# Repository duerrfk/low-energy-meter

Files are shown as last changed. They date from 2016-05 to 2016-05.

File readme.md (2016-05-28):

# What is Low-Energy-Meter?

Low-Energy-Meter is a tool for measuring the energy consumption of low-energy devices using a Raspberry Pi. In particular, it was developed to measure the energy consumption of battery-powered Bluetooth Low Energy (BLE) devices.

Low-energy devices switch frequently between active mode and power-save mode striving for minimum duty cycles. The energy consumption differs significantly by several orders of magnitude between active mode and power-save mode (milli-amps vs. micro-amps). This makes energy measurements challenging. For instance, it is hard to dimension a shunt resistor for measuring the voltage drop along the resistor to calculate current as I = V/R. If the shunt resistor is optimized for active mode, the voltage drop will be very low in power-save mode and thus hard to measure. If the shunt resistor is optimized for power-save mode, the voltage drop will be very large in active mode, and the device only runs at significantly reduced voltage possibly dropping below the threshold where brownout reset engages. 

Therefore, we use a different method to measure the energy consumption. We use a large capacitor (C = 10000 uF) as power supply. The energy stored in a capacitor can be calculated as E = 0.5\*C\*V^2. Thus, knowing the time period (t) that it takes to drop from a certain initial voltage (V_upper) to a certain lower voltage (V_lower), we can calculate the energy consumed in period t as E_delta = 0.5\*C\*(V_upper^2-V_lower^2) and the average power consumption as P_avg = E_delta/t. The energy consumption naturally includes the energy spent in active mode as well as power-save mode. So the basic idea is to first charge the capacitor from a "real" power supply (voltage regulator of the Raspberry Pi) and then discharge the capacitor via the device under test. While discharging, we periodically measure the voltage of the capacitor. When the voltage drops below a certain threshold somewhere above the critical brownout detection threshold, we automatically charge the capacitor again and start a new measuring cycle. 

One might argue that the capacitor is prone to self-discharging. However, experiments showed that this effect is very small, even smaller than the energy consumption in power-save mode and much smaller than the energy consumption in active mode, and thus negligible for our purpose. TODO: Prove this claim.

Low-Energy-Meter consists of two parts:

* Measurement hardware connected to the Raspberry Pi. The measurement hardware is basically a circuit board (PCB) with an analog-to-digital converter (ADC), the 10000 uF supply capacitor and some more components to support automatic measurements by repeatedly charging the supply capacitor and sampling the capacitor voltage while discharging the capacitor. The measurement board is depicted in the images below with a simple resistor connected as load ("device under test"). Schematics and PCB layout of the PCB are included.
* Software for the Raspberry Pi that automates the process of charging and sampling the supply capacitor and logging samples to the SD card.

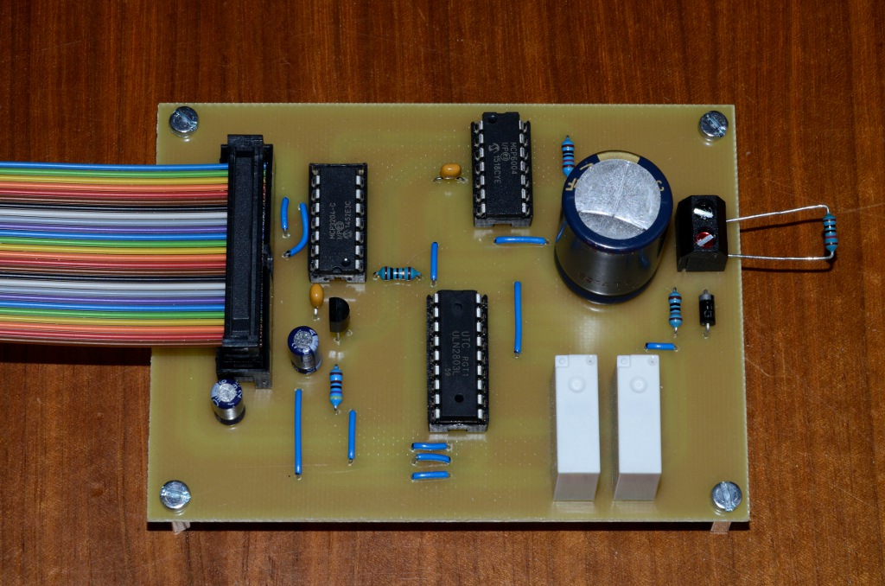
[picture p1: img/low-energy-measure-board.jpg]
Measurement Board


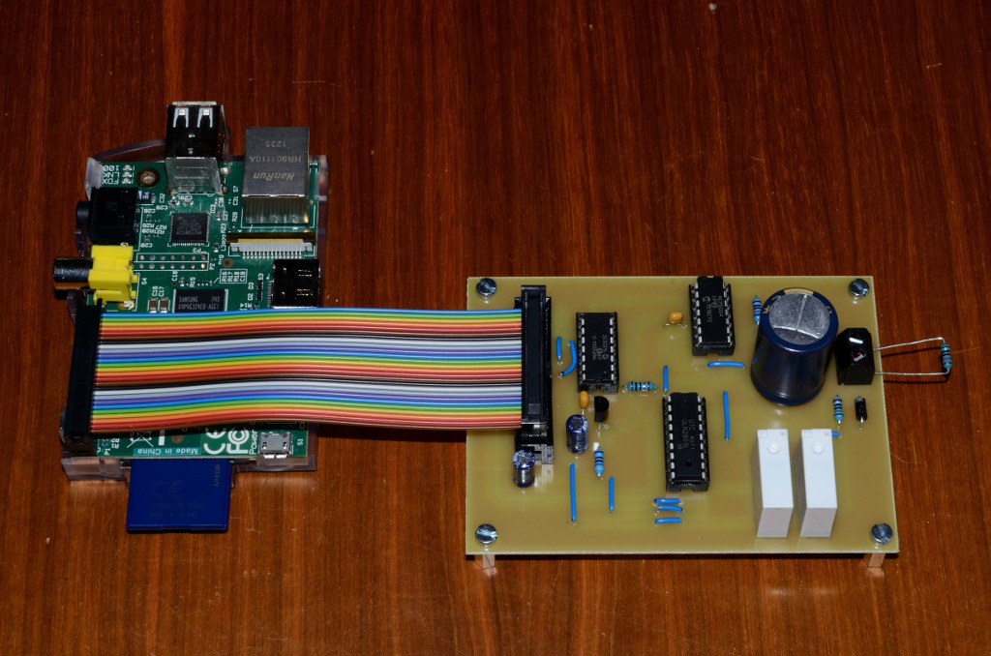
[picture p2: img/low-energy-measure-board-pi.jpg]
Measurement Board connected to Raspberry Pi


# The Hardware: Measurement Board

We use a capacitor of 10000 uF to power the device under test. This is large enough to run a BLE device for several minutes (using reasonable power-saving techniques) while voltage drops from say 3.0 V to 2.0 V. This capacitor is charged via a 160 Ohm resistor making sure not to overload the 3.3 V power rail of the Raspberry Pi. Since we charge the capacitor from the 3.3 V rail, 3.3 V is the maximum voltage we can supply to the device under test. For the BLE target devices and most MCUs this is a suitable voltage.
 
The measurement board is connected to a Raspberry Pi Model B (a single core Pi is good enough for 1 kHz sampling rate). It includes a 12 bit ADC (MCP6008 or MCP6004) to sample the voltage of the supply capacitor and transmit voltage samples to the Raspberry Pi via SPI.

Moreover, it includes two relays, one for charging the capacitor and powering the device under test while charging, and one for connecting the supply capacitor to the device under test when the capacitor has been charged for measuring the energy consumption. Both relays are controlled from two GPIOs of the Raspberry Pi to automate the process of charging and sampling while discharging the capacitor. An ULN2803 is used to drive the relays. 

A precise 2.5 V voltage reference (LM385) is used as reference for the ADC.

The board layout is optimized for simple etching (alternatively, you can send the Gerber files to a PCB manufacturer of your choice). Moreover, we only use easily available standard components. 

# The Software

Low-Energy-Meter includes a command line tool to automate the process of charging and sampling the supply capacitor and logging samples to a file.

The software tool called low-energy-meter can be found in folder src. 

## Compiling Low-Energy-Meter Tool

As a prerequisite, you need the [bcm2835 library](http://www.airspayce.com/mikem/bcm2835/). After installing the library, you can compile the tool with the following command:

    $ make low-energy-meter

## Running Low-Energy-Meter Tool

For precise sampling intervals, we recommend to use the RTPREEMPT patch for Linux (instructions on how to compile an RTPREEMPT kernel can be found on [this web-site](http://www.frank-durr.de/?p=203). 

The command line tool uses the following arguments:

* ```-f SAMPLING_FREQUENCY```: Sampling frequency. 1 kHz seems to be a safe upper bound where the Raspberry Pi can still deterministically meet the 1 ms sampling interval.
* ```-o FILE```: Output file for logging samples.
* ```-l THRESHOLD_LOWER```: Lower voltage threshold (ADC count) defining when the supply capacitor is recharged.
* ```-u THRESHOLD_UPPER```: Upper threshold (ADC count) defining when a discharging (sampling) cycle starts.

ADC counts can be translated to voltage thresholds as follows: V = 5.0 V \* 4095/ADCCount

Note that the reference voltage of the ADC is 2.5 V and we divide the voltage sampled by the ADC by 2 to stay within the allowed voltage range of max. 2.5 V. Therefore, an ADC count of 4095 corresponds to 5 V.  
    
The format of the output file is CSV (comma-separated values) with the following values per sample: 

* Timestamp of the sample in nanoseconds.
* Epoch (discharging cycle). Measurements are only recorded while discharging, i.e., while powering the device under test from the capacitor.
* ADC count, which can be translated to capacitor voltage by calculating V = 5.0 V \* 4095/ADCCount.

# Measurement Example

The following example shows how to take measurements, and how to evaluate them using [R](https://www.r-project.org/). In this example, we measure the energy-efficiency of the [Faros]() Bluetooth Low Energy Beacon implementing Google's Eddystone standard. The data of this experiment is available in folder data. 

## Step 1: Taking measurements

We take measurements with 1000 Hz sampling frequency, and lower and upper voltage thresholds of 2.0 V (ADC count = 2.0 V / 5.0 V \* 4095 = 1638) and 3.2 V (ADC count = 2621), respectively, i.e., the device under test is running from voltages in this range. The Faros beacon can be operated down to 1.8 V, so re-charging the capacitor at 2.0 V leaves enough headroom to ensure that the beacon will not reset. We also provide the data set of this experiment in folder data, so you can follow the steps below.

    $ sudo ./low-energy-meter -f 1000 -l 1638 -u 2621 -o faros.csv -p 80

## Step 2: Loading the CSV data into R.

    $ R
    $ x <- read.csv(file="faros.csv",head=FALSE,sep=",")

After this step, you will find all data in data frame x, which is basically a table with three rows called x$V1 (timestamp in nanoseconds), x$V2 (measurement cycle), and x$V3 (ADC count of voltage measurements).

## Step 3: Selecting data for evaluation

We will select data from one measurement cycle in a certain voltage range between 2.0 V (ADC count 1638) and 3.0 V (ADC count 2457).

    $ y = subset(x, x$V2==2 & x$V3 >= 1638 & x$V3 <= 2457)

The selected data is now in data frame y. For visual inspection, you can plot the voltage (ADC counts) over time using the following command:

    $ plot(y$V1/1000000000-min(y$V1)/1000000000, y$V3/4095*5.0, xlab="t [s]", ylab="Voltage [V]")

The following plot shows the measurements taken for the Faros beacon.

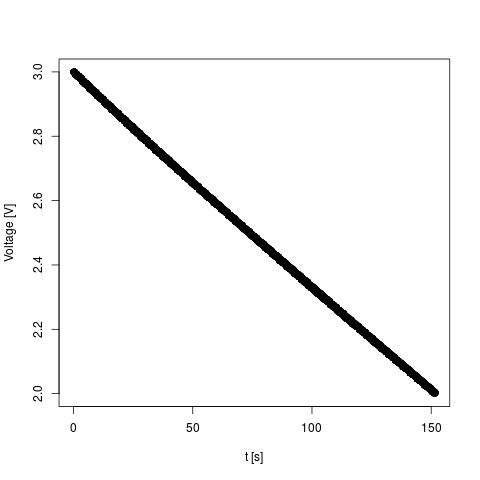
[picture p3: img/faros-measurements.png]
Faros beacon measurements


## Step 4: Calculating consumed energy and average power consumption

First, we determine the maximum and minumum voltage of the selected sample interval:

    $ max(y$V3)
    [1] 2457
    $ min(y$V3)
    [1] 1638

So the maximum and minumum voltages are V_max = 2457/4095 \* 5.0 V = 3.0 V and V_min = 1638/4095 \* 5.0 V = 2.0 V, respectively.

Then, we calculate the time t that it took to drop from V_max to V_min:

    $ (max(y$V1)-min(y$V1))/1000000000
    151.715
 
So it took t = 151.715 s.

Since we know the capacity of the supply capacitor (10000 uF), we can calculatete the energy spent in this time interal as:

E = 0.5\*10000 uF\*(3.0 V)^2 - 0.5\*10000 uF\*(2.0 V)^2 = 0.025 J

The average power consumption is then calculated as:

P_avg = E/t = 0.025 J / 151.715 s = 164.78 uW

So if the Faros BLE beacon is powered from AA-size batteries (two connected in series to provide a nominal voltage of 3.0 V) with say 2.60 Wh energy, the beacon could run for about 657 days or 1.8 years.

# Voltage Leakage

One might argue that this measurement method is prone to inaccuracies because of self-discharging effects, bias current flowing into or out of the opamp connected to the capacitor (which according to the datasheet of the MCP6001 should be in the order of pA, so possibly not the biggest effect), etc. In order to evaluate these undesired effects, we took measurements without any load connected, where we would expect (ideally) the power consumption to be zero. The data is included in the data folder. The figure below depicts the result.

We can see that the capacitor discharged from initially V_max = 3.300 V to V_min = 3.066 V over a time period of t = 27926 s = 7.76 h. Hence, the energy consumed in this period is 0.0074 J, and the average power consumption is 266.713 nW. So giving some safety-margin, we can assume an accuracy of power measurements of about 1 uW. 

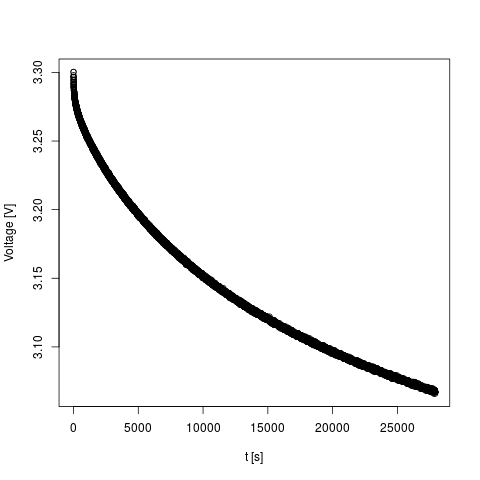
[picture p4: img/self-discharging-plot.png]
Self-discharging of capacitor


# Limitations

This measurement method is targeting low-energy devices, in particular, BLE devices. We make the following assumptions:

* The device under test can run from varying voltages in a range from 3.3 V to some lower threshold. Typical lower thresholds of MCUs used in BLE devices are as low as 1.8 V. For devices requiring more than 3.3 V (like for instance a Raspberry Pi, which is powered from 5.0 V USB), the circuit is not suitable.
* The device under test consumes little power up to tens of milliamps over the desired voltage range. Otherwise, the supply capacitor does not provide enough energy to run the device for a longer period including all operational modes (active and power-save mode). Up to tens of milliamps are typical values for active BLE devices with active MCU and radio (in power-save mode, the current is much lower down to micro-amps).    

# Licensing

Low-Energy-Meter uses two licenses for open hardware and software, respectively:

* The software (source code) is licensed under the Apache License 2.0
* The hardware (schematic diagrams, circuit board layouts, hardware documentation) is licensed under the CERN Open Hardware Licence v1.2

Both licenses are included in the repository.

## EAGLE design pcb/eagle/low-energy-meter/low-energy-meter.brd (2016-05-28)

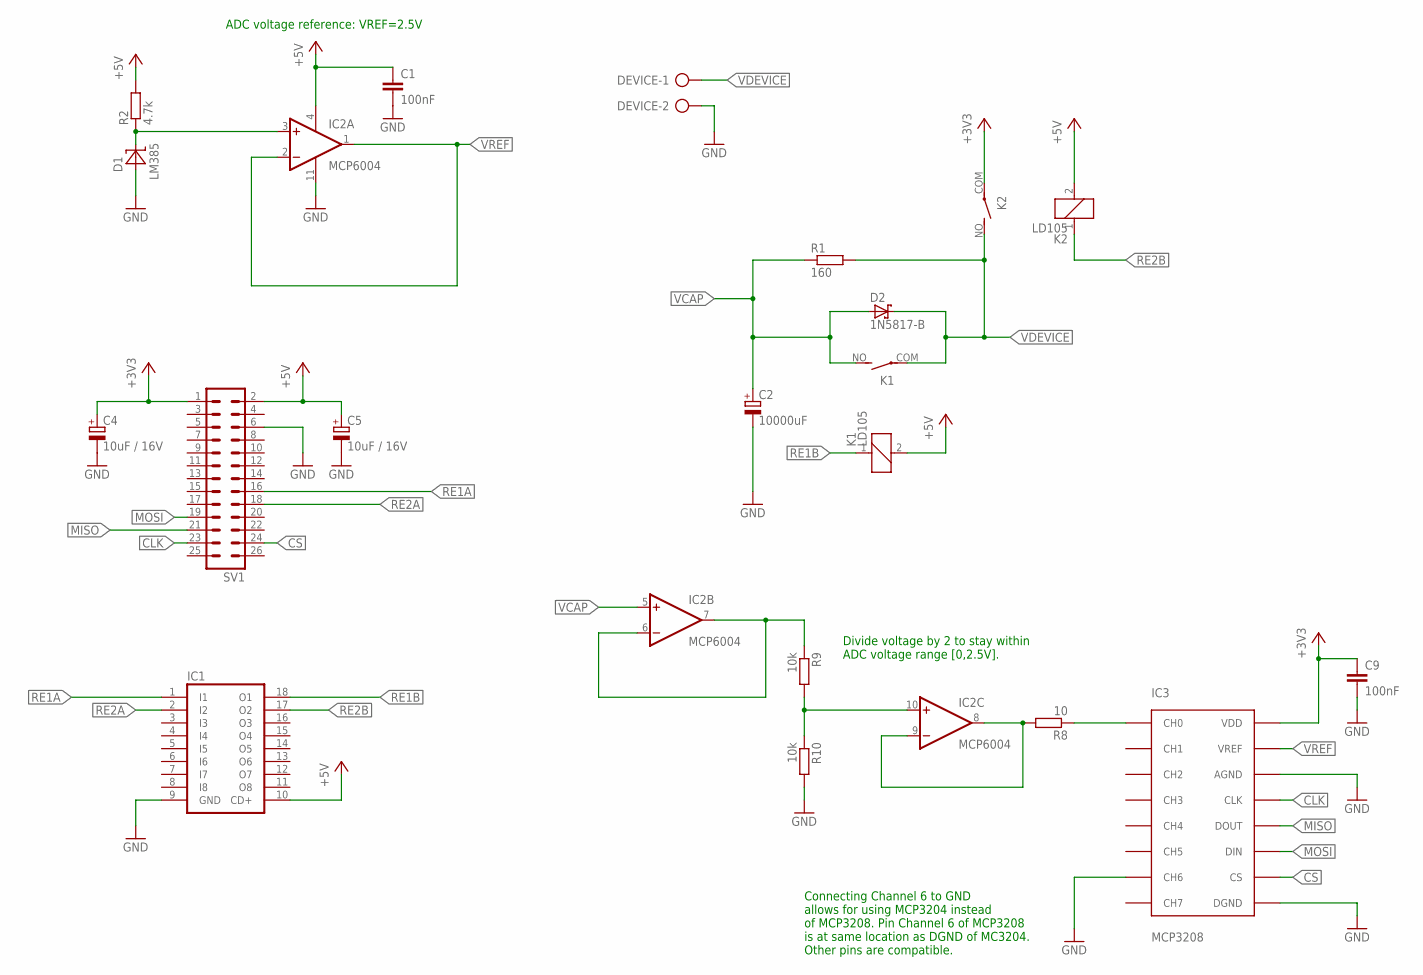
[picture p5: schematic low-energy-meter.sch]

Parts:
C1, C9: 100nF; C050-024X044
C2: 10000uF; E7,5-18
C4, C5: 10uF / 16V; E2,5-6
D1: LM385; TO-92
D2: 1N5817-B; DO41-7.6
DEVICE: AK500/2
IC1: ULN2803A; DIL18
IC2: MCP6004; DIL14
IC3: MCP3208; DIL16
K1, K2: LD105; LD
R1: 160; 0207/7
R2: 4.7k; 0207/7
R8: 10; 0207/7
R9, R10: 10k; 0207/7
SV1: ML26

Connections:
+3V3: C4.+, C9.1, IC3.VDD, K2.COM, SV1.1
+5V: C1.1, C5.+, IC1.10 (CD+), IC2.4 (V+), K1.2, K2.2, R2.2, SV1.2
CLK: IC3.CLK, SV1.23
CS: IC3.CS, SV1.24
GND: C1.2, C2.-, C4.-, C5.-, C9.2, D1.+, DEVICE.2, IC1.9 (GND), IC2.11 (V-), IC3.AGND, IC3.CH6, IC3.DGND, R10.2, SV1.6
MISO: IC3.DOUT, SV1.21
MOSI: IC3.DIN, SV1.19
unnamed: IC2.6 (-IN), IC2.7 (OUT), R9.1
unnamed: IC2.10 (+IN), R9.2, R10.1
unnamed: IC3.CH0, R8.1
unnamed: IC2.8 (OUT), IC2.9 (-IN), R8.2
unnamed: D1.-, IC2.3 (+IN), R2.1
RE1A: IC1.1 (I1), SV1.16
RE1B: IC1.18 (O1), K1.1
RE2A: IC1.2 (I2), SV1.18
RE2B: IC1.17 (O2), K2.1
VCAP: C2.+, D2.A, IC2.5 (+IN), K1.NO (S), R1.1
VDEVICE: D2.C, DEVICE.1, K1.COM, K2.NO (S), R1.2
VREF: IC2.1 (OUT), IC2.2 (-IN), IC3.VREF

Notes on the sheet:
ADC voltage reference: VREF=2.5V
Divide voltage by 2 to stay within ADC voltage range [0,2.5V].
Connecting Channel 6 to GND allows for using MCP3204 instead of MCP3208. Pin Channel 6 of MCP3208 is at same location as DGND of MC3204. Other pins are compatible.

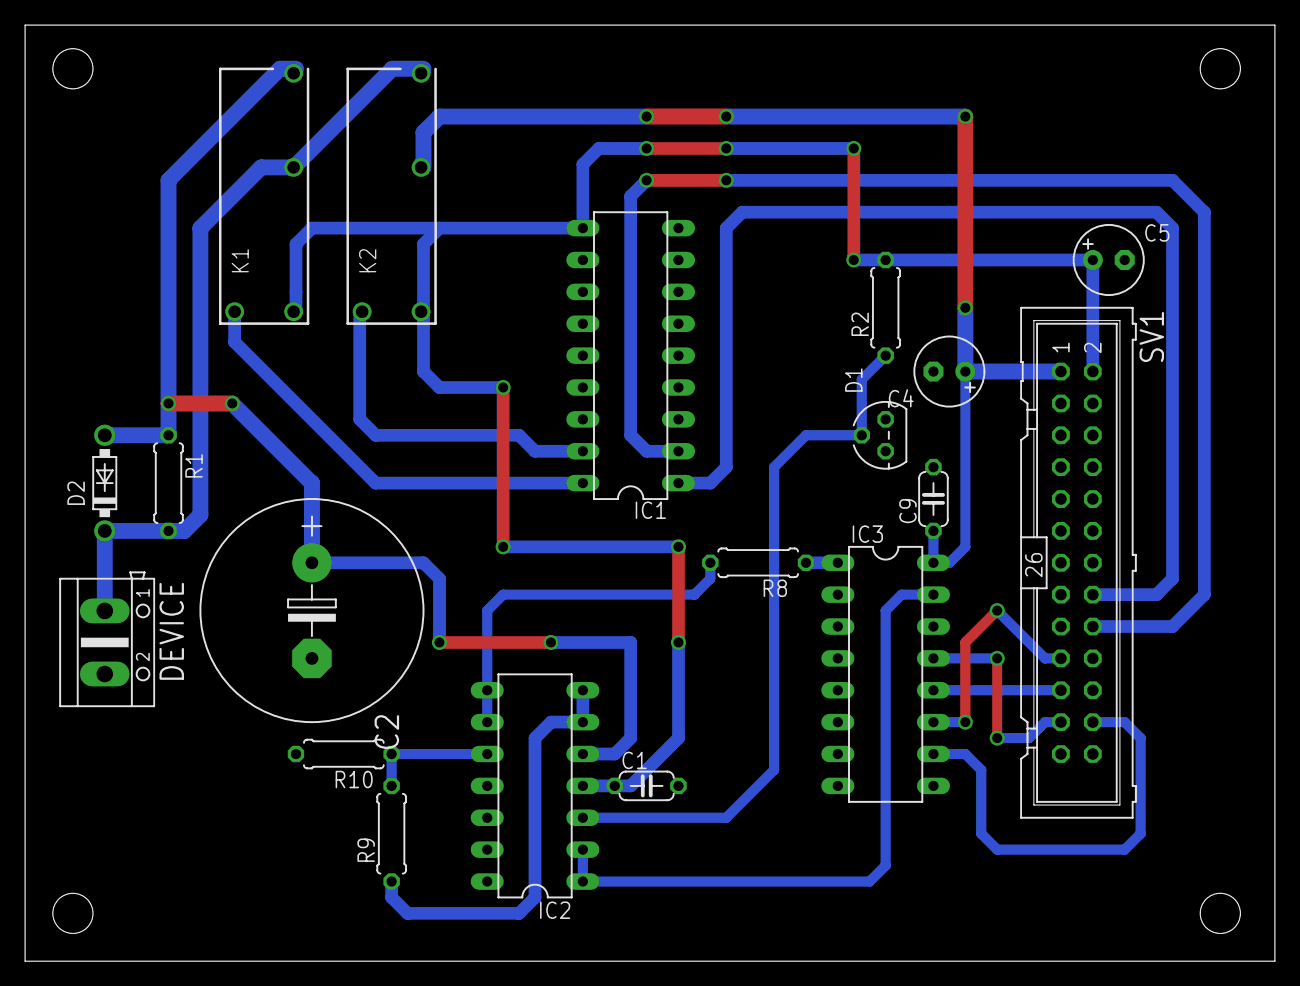
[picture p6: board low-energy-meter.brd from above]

Board: 2 copper layers, 99.6 x 74.6 mm, 19 parts (0 on the bottom side), 19 nets.

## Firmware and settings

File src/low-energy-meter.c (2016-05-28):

/**
 * This file is part of Low-Energy-Meter.
 *
 * Copyright 2016 Frank Dürr
 *
 * Licensed under the Apache License, Version 2.0 (the "License");
 * you may not use this file except in compliance with the License.
 * You may obtain a copy of the License at
 * 
 * http://www.apache.org/licenses/LICENSE-2.0
 * 
 * Unless required by applicable law or agreed to in writing, software
 * distributed under the License is distributed on an "AS IS" BASIS,
 * WITHOUT WARRANTIES OR CONDITIONS OF ANY KIND, either express or implied.
 * See the License for the specific language governing permissions and
 * limitations under the License.
 */

#include <bcm2835.h>
#include <stdlib.h>
#include <unistd.h>
#include <stdio.h>
#include <string.h>
#include <time.h>
#include <stdbool.h>
#include <signal.h>
#include <sched.h>
#include <sys/mman.h>
#include <stdbool.h>
#include "mcp320x.h"
#include "ring.h"

/* Default task priority */
#define DEFAULT_TASK_PRIORITY 49

/* Estimated maximum stack size */
#define MAX_STACK_SIZE (RING_SIZE*sizeof(struct ring_entry) + 1024) 

/* GPIO pins controlling charge and discharge relay */
const RPiGPIOPin charge_pin = RPI_GPIO_P1_18; 
const RPiGPIOPin discharge_pin = RPI_GPIO_P1_16; 

/* ADC channel measuring voltage of capacitor / device */
const enum channel_singleended adc_channel = CH0;

/* SPI settings. */
/* The Raspberry Pi has two SS pins called CE0 and CE1. 
   The board uses CE0 (BCM2835_SPI_CS0). */
const bcm2835SPIChipSelect spi_cs = BCM2835_SPI_CS0;
/* Since we operate the MCP3208 at 3.3 V, the SPI clock rate should be <= 1 MHz 
   (cf. MCP3208 datasheet). 500 kHz should be a safe setting. */
const unsigned int spi_frequency = 500000;

FILE *fout = NULL;

int task_priority;
struct timespec sampling_interval;
double sampling_frequency;

uint16_t threshold_upper;
uint16_t threshold_lower;

struct ring the_ring;

pthread_t sampling_thread;
pthread_t logger_thread;

bool is_spi_open = false;
bool is_bcm_open = false;

/**
 * Gracefully terminate the process.
 *
 * @param status process exit status
 */
void die(int status)
{
     if (fout != NULL)
	  fclose(fout);

     if (is_spi_open)
	  bcm2835_spi_end();

     if (is_bcm_open)
	  bcm2835_close();
     
     exit(status);
}

/**
 * SIGINT signal handler.
 */
void sig_int(int signo)
{
     pthread_cancel(sampling_thread);
     pthread_cancel(logger_thread);
}

/**
 * Print usage information.
 */
void usage(const char *appl)
{
     fprintf(stderr, "%s -f SAMPLING_FREQUENCY -l LOWER_THRESHOLD "
	     "-u UPPER_THRESHOLD -o LOGFILE [-p TASK_PRIORITY] \n", appl);
}

/**
 * Pref-fault stack memory for deterministic time to access stack memory.
 */
void stack_prefault(void)
{
     unsigned char dummy[MAX_STACK_SIZE];
     memset(dummy, 0, MAX_STACK_SIZE);
     return;
}

/**
 * Convert a frequency value to a time interval.
 *
 * @param frequency frequency in Hertz
 * @return time interval
 */
struct timespec frequency_to_interval(double frequency)
{
     struct timespec itimespec;
     
     /* Calculate interval in nanoseconds.
        A 64 bit value is enough for thousands of years sampling. */
     uint64_t ins = (uint64_t) (1000000000.0/frequency + 0.5);

     itimespec.tv_sec = ins/1000000000ull;
     itimespec.tv_nsec = ins%1000000000ull;

     return itimespec;
}

/**
 * Calculate timestamp of next sample.
 *
 * @param tlast time of last sample
 * @param interval sampling interval
 * @return time of next sample
 */
struct timespec next_sampling_time(struct timespec tlast,
				   struct timespec interval)
{
     struct timespec tnext;
     
     tnext.tv_sec = tlast.tv_sec+interval.tv_sec;
     tnext.tv_nsec = tlast.tv_nsec+interval.tv_nsec;

     /* Normalize */
     if (tnext.tv_nsec >= 1000000000l) {
	  tnext.tv_sec++;
	  tnext.tv_nsec -= 1000000000l;
     }

     return tnext;
}

/**
 * Convert timespec values (sec, ns) to 64 bit nanosecond value.
 *
 * @param t timespec values
 * @return value in nanoseconds corresponding to timespec values
 */
uint64_t to_nanosec(struct timespec t)
{
     uint64_t t_ns = 1000000000ull*t.tv_sec;
     t_ns += t.tv_nsec;

     return t_ns;
}

/**
 * Write timestamped samples as CSV to log file.
 *
 * Format: comma-separated values 
 * timestamp [nanoseconds], value 
 *
 * @param fout output file
 * @param sample sample value
 * @param tsample timestamp of sample
 */
void log_sample(FILE *fout, int16_t sample, uint64_t t, uint64_t epoch)
{
     fprintf(fout, "%llu,%llu,%d\n", t, epoch, sample);
}

/**
 * Main loop of sampling thread.
 */
void *sampling_thread_loop(void *args)
{
     /* Set high ("realtime") priority for sampling thread */

     struct sched_param schedparam;
     schedparam.sched_priority = task_priority;
     if (sched_setscheduler(0, SCHED_FIFO, &schedparam) == -1) {
	  perror("sched_setscheduler failed");
	  die(-1);
     }

     /* Start infinite loop of charging-discharging cycles until user 
	interrupts. */

     /* Start in charge state */ 
     struct timespec twait;
     enum State {charging, discharging} state = charging;
     // CAUTION: First open discharge relay before closing charge
     // relay! Otherwise, a high current might flow into to
     // discharged capacitor by-passing the limiting resistor.
     bcm2835_gpio_clr(discharge_pin);
     // Wait 100 ms to be sure that discharge relay is open
     // (relay should open within less than 10 ms
     // according to datasheet, so 100 ms should be safe).
     twait.tv_sec = 0;
     twait.tv_nsec = 100000000;
     clock_nanosleep(CLOCK_MONOTONIC, 0, &twait, NULL);
     bcm2835_gpio_set(charge_pin);

     uint64_t epoch = 0;
     struct timespec tsample;
     clock_gettime(CLOCK_MONOTONIC, &tsample);
     while (true) {
	  // Take a sample 
	  int16_t sample = get_sample_singleended(adc_channel);

	  // Timestamp sample
	  struct timespec tnow;
	  clock_gettime(CLOCK_MONOTONIC , &tnow);
	       
	  if (sample == -1) {
	       fprintf(stderr, "Error while taking sample\n");
	  } else if (state == charging) {
	       // Stop charging when upper threshold was passed and then
	       // switch to discharging phase.
	       if (sample >= threshold_upper) {
		    // Charged. Switch to discharging phase.
		    state = discharging;
		    // CAUTION: First open charge relay before closing discharge
		    // relay! Otherwise, a high current might flow into to
		    // capacitor by-passing the limiting resistor.
		    bcm2835_gpio_clr(charge_pin);
		    // Wait 100 ms to be sure that charge relay is open
		    // (relay should open within less than 10 ms
		    // according to datasheet, so 100 ms should be safe).
		    twait.tv_sec = 0;
		    twait.tv_nsec = 100000000;
		    clock_nanosleep(CLOCK_MONOTONIC, 0, &twait, NULL);
		    bcm2835_gpio_set(discharge_pin);
		    // New sampling period starts now (right before taking
		    // next sample).
		    epoch++;
		    clock_gettime(CLOCK_MONOTONIC, &tsample);
	       } else {
		    // Go on charging.
		    // Sleep until next sampling time
		    tsample = next_sampling_time(tsample, sampling_interval);
		    clock_nanosleep(CLOCK_MONOTONIC, TIMER_ABSTIME, &tsample, 
				    NULL);
	       }
	  } else if (state == discharging) {
	       // Record sample.
	       struct ring_entry entry;
	       entry.timestamp = to_nanosec(tnow);
	       entry.value = sample;
	       entry.epoch = epoch;
	       ring_put(&the_ring, &entry);

	       // Switch to charging phase when lower threshold was passed.
	       if (sample <= threshold_lower) {		    
		    // Discharged. Switch to charging phase.
		    state = charging;
		    // CAUTION: First open discharge relay before closing 
		    // charge relay! Otherwise, a high current might flow into 
		    // to discharged capacitor by-passing the limiting resistor.
		    bcm2835_gpio_clr(discharge_pin);
		    // Wait 100 ms to be sure that discharge relay is open
		    // (relay should open within less than 10 ms
		    // according to datasheet, so 100 ms should be safe).
		    twait.tv_sec = 0;
		    twait.tv_nsec = 100000000;
		    clock_nanosleep(CLOCK_MONOTONIC, 0, &twait, NULL);
		    bcm2835_gpio_set(charge_pin);			 
	       } else {
		    // Go on discharging.
		    // Sleep until next sampling time
		    tsample = next_sampling_time(tsample, sampling_interval);
		    clock_nanosleep(CLOCK_MONOTONIC, TIMER_ABSTIME, &tsample, 
				    NULL);
	       }
	  }
     }
}

/**
 * Main loop of logger thread.
 */
void *logger_thread_loop(void *args)
{
     /* Set high ("realtime") priority for sampling thread */

     struct sched_param schedparam;
     /* Give logger thread a lower priority than sampling thread, so on a 
        single core system it does not get into the way of the sampling
	thread. */ 
     schedparam.sched_priority = task_priority-1;
     if (sched_setscheduler(0, SCHED_FIFO, &schedparam) == -1) {
	  perror("sched_setscheduler failed");
	  die(-1);
     }
     
     while (true) {
	  struct ring_entry entry;
	  ring_get(&the_ring, &entry);
	  log_sample(fout, entry.value, entry.timestamp, entry.epoch);
     }
}

/* Configure GPIO pins controlling charge and discharge relays */
void setup_gpio()
{
     bcm2835_gpio_fsel(charge_pin, BCM2835_GPIO_FSEL_OUTP);
     bcm2835_gpio_clr(charge_pin);

     bcm2835_gpio_fsel(discharge_pin, BCM2835_GPIO_FSEL_OUTP);
     bcm2835_gpio_clr(discharge_pin);
}

/**
 * The main function.
 */
int main(int argc, char *argv[])
{
     /* Parse command line arguments */
     
     char *sampling_frequency_arg = NULL;
     char *logfile_arg = NULL;
     char *threshold_upper_arg = NULL;
     char *threshold_lower_arg = NULL;
     char *task_priority_arg = NULL;
     int c;
     while ((c = getopt(argc, argv, "f:o:p:l:u:")) != -1) {
	  switch (c) {
	  case 'f' :
	       sampling_frequency_arg = malloc(strlen(optarg)+1);
	       strcpy(sampling_frequency_arg, optarg);
	       break;
	  case 'o' :
	       logfile_arg = malloc(strlen(optarg)+1);
	       strcpy(logfile_arg, optarg);
	       break;
	  case 'l' :
	       threshold_lower_arg = malloc(strlen(optarg)+1);
	       strcpy(threshold_lower_arg, optarg);
	       break;
	  case 'u' :
	       threshold_upper_arg = malloc(strlen(optarg)+1);
	       strcpy(threshold_upper_arg, optarg);
	       break;
	  case 'p' :
	       task_priority_arg = malloc(strlen(optarg)+1);
	       strcpy(task_priority_arg, optarg);
	       break;
	  case '?':
	       fprintf(stderr, "Unknown option\n");
	       usage(argv[0]);
	       die(-1);
	       break;
	  }
     }
	      
     if (sampling_frequency_arg == NULL || logfile_arg == NULL ||
	 threshold_lower_arg == NULL || threshold_upper_arg == NULL) {
	  usage(argv[0]);
	  die(-1);
     }

     threshold_lower = atoi(threshold_lower_arg);
     threshold_upper = atoi(threshold_upper_arg);
     sampling_frequency = strtod(sampling_frequency_arg, NULL);
     sampling_interval = frequency_to_interval(sampling_frequency);

     if (task_priority_arg != NULL) {
	  task_priority = atoi(task_priority_arg);
     } else {
	  task_priority = DEFAULT_TASK_PRIORITY;
     }
     
     /* Setup SPI */

     if (bcm2835_init() == 0) {
	  die(-1);
     } else {
	  is_bcm_open = true;
     }
     
     bcm2835_spi_begin();
     is_spi_open = true;
     
     bcm2835_spi_chipSelect(spi_cs);

     // Set divider according to SPI frequency
     uint16_t divider = (uint16_t) ((double) 250000000/spi_frequency + 0.5);
     bcm2835_spi_setClockDivider(divider);

     // SPI 0,0 as per MCP3208 data sheet
     bcm2835_spi_setDataMode(BCM2835_SPI_MODE0);

     bcm2835_spi_setBitOrder(BCM2835_SPI_BIT_ORDER_MSBFIRST);

     bcm2835_spi_setChipSelectPolarity(BCM2835_SPI_CS0, LOW);

     // Configure GPIO pins as output and set output to low.
     setup_gpio();
     
     /* Open log file */

     fout = fopen(logfile_arg, "w");
     if (fout == NULL) {
	  perror("Could not open log file");
	  die(-1);
     }

     // Init ring buffer for communicate between sampling and logging threads.

     ring_init(&the_ring);

     /* Lock memory and prefault stack */

     if (mlockall(MCL_CURRENT|MCL_FUTURE) == -1) {
	  perror("mlockall failed");
	  die(-1);
     }

     stack_prefault();
     
     /* Create threads */
     
     if (pthread_create(&sampling_thread, NULL, sampling_thread_loop, NULL)) {
	  perror("Could not create sampling thread");
	  die(-1);
     }

     if (pthread_create(&logger_thread, NULL, logger_thread_loop, NULL)) {
	  perror("Could not create logger thread");
	  die(-1);
     }

     /* Install SIGINT signal handler for graceful termination */
     
     if (signal(SIGINT, sig_int) == SIG_ERR) {
	  perror("Could not set signal handler for SIGINT");
	  die(-1);
     }
     
     pthread_join(logger_thread, NULL);
     pthread_join(sampling_thread, NULL);

     die(0);
}

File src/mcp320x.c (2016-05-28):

/**
 * This file is part of Low-Energy-Meter.
 *
 * Copyright 2016 Frank Dürr
 *
 * Licensed under the Apache License, Version 2.0 (the "License");
 * you may not use this file except in compliance with the License.
 * You may obtain a copy of the License at
 * 
 * http://www.apache.org/licenses/LICENSE-2.0
 * 
 * Unless required by applicable law or agreed to in writing, software
 * distributed under the License is distributed on an "AS IS" BASIS,
 * WITHOUT WARRANTIES OR CONDITIONS OF ANY KIND, either express or implied.
 * See the License for the specific language governing permissions and
 * limitations under the License.
 */

#include "mcp320x.h"

#include <bcm2835.h>

const uint8_t startbit = 0x80;
const uint8_t sebit = 0x40;

/**
 * Request a sample from MCP320x.
 * 
 * @param channel_config the 3 channel configuration bits as defined
 * in the MCP3204/3208 data sheet.
 * @return 12 bit sample value, or -1 in case of an error.
 */
int16_t sample(uint8_t channel_config)
{
     uint8_t config = startbit | sebit | (channel_config << 3);

     uint16_t s;
     uint8_t data[3];
     data[0] = config;
    
     /* This function will overwrite the given data with the received data. */
     bcm2835_spi_transfern((char *) data, 3);

     /* 12 bit sample is returned most-significant bit first, 7 bit
	times after sending the config bits. */
     s = ((uint16_t) (data[0]&0x01)) << 11;
     s |= (uint16_t) (data[1]) << 3;
     s |= (uint16_t) ((data[2]&0xe0) >> 5);

     return ((int16_t) s);
}

int16_t get_sample_singleended(enum channel_singleended adc_channel)
{
     uint8_t channel;
     switch (adc_channel) {
     case CH0:
	  channel = 0;
	  break;
     case CH1:
	  channel = 1;
	  break;
     case CH2:
	  channel = 2;
	  break;
     case CH3:
	  channel = 3;
	  break;
     case CH4:
	  channel = 4;
	  break;
     case CH5:
	  channel = 5;
	  break;
     case CH6:
	  channel = 6;
	  break;
     case CH7:
	  channel = 7;
	  break;
     default:
	  return -1;
     }

     return sample(channel);
}

int16_t get_sample_diff(enum channel_differential adc_channel)
{
     uint8_t channel;
     switch (adc_channel) {
     case CH0CH1 :
	  channel = 0;
	  break;
     case CH1CH0 :
	  channel = 1;
	  break;
     case CH2CH3 :
	  channel = 2;
	  break;
     case CH3CH2 :
	  channel = 3;
	  break;
     case CH4CH5 :
	  channel = 4;
	  break;
     case CH5CH4 :
	  channel = 5;
	  break;
     case CH6CH7 :
	  channel = 6;
	  break;
     case CH7CH6 :
	  channel = 7;
	  break;
     default:
	  return -1;
     }

     return sample(channel);
}
